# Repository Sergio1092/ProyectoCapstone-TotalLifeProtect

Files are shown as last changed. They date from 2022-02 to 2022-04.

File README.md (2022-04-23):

# **Monitoreo de la calidad del aire utilizando como indicadores la concentración de CO, CO2 y GLP**



## Proyecto Capstone del Diplomado "Internet de las Cosas" de Samsung Innovation Campus y CodigoIoT.

> Integrantes: 
> 
> Cruz Varela Karen Guerlain, UAM Azcapotzalco, Ing. en Computación.
> 
> Zárate Chávez Tania Guadalupe, UAM Azcapotzalco, Ing. en Computación.
> 
> Delgadillo Marín Sergio, UAM Azcapotzalco, Ing. en Computación.
> 
> - Asesor: Vilchis León Paloma Alejandra. 
> 
> Para **contactar** a cualquier integrante, lo puedes hacer a través de correo electrónico:
> 
> **Tania Zárate:** zarate.tania.ch@gmail.com
> 
> **Sergio Delgadillo:** al2162000251@azc.uam.mx, sergio.delgadillo@cinvestav.mx
> 
> **Karen Cruz:** karenmuse.99@gmail.com

# Introducción

Cuando se detecta cierta cantidad de humo y una cantidad de CO alto hace que esto sea nocivo para la salud, lo cual puede provocar:
- Intoxicación.
- Asfixia.
- Crisis nerviosa.
- Tos.
- Entre otros.

La **intoxicación por monóxido de carbono** sucede cuando se acumula CO en el torrente sanguíneo. Cuando hay demasiado monóxido de carbono en el aire, el cuerpo reemplaza el oxígeno en los glóbulos rojos con monóxido de carbono. Esto puede generar un **daño grave** en el tejido, o incluso desmayos y, en el peor de los casos, **muerte por asfixia**. Para evitar llegar a tal tragedia, es altamente recomendable tener el *espacio ventilado*, de esta manera, se evita la acumulación de monóxido de carbono en el lugar donde se resida o donde se labore.

Al igual que el monóxido de carbono, el **gas licuado de petróleo (GLP)**, que es una mezcla de propano y butano, al inhalarlo puede causar *euforia, somnolencia, inconsciencia, asfixia, trastornos del ritmo cardíaco, fluctuaciones en la presión sanguínea*, y puede resultar en la **muerte por _asfixia_ y fibrilación ventricular**.

Por otro lado, la pandemia mundial actualmente en curso derivada de la enfermedad ocasionada por el virus *SARS-CoV-2*, continúa afectando a la humanidad, a pesar de contar con alguna vacuna o el esquema de vacunación completo. Los contagios no sólo se han dado por la interacción entre personas, también es debido a la inhalación de partículas en el aire que contienen el virus, más en habitaciones que no cuentan con la ventilación adecuada, ya sea que no cuenten con aire acondicionado o simplemente que no tengan ventanas. Se pueden analizar los **niveles de CO2** para saber si la habitación se está llenando de *exhalaciones infecciosas*. El nivel de este componente permite estimar si entra suficiente aire fresco del exterior.

En cuanto a la relación con PNUD, el proyecto como tal se encuentra ubicado en el tercer objetivo de Desarrollo Sostenible, el cual es “Salud y Bienestar”, ya que Total Life Protect permite la **detección de humo, gas, CO y CO2** que pueden llegar a afectar al ser humano dentro del hogar debido a un mal uso de electrodomésticos o dispositivos necesarios en la vida diaria, además de evitar contagios y posibles muertes por el virus SARS-CoV-2 ya que determina la calidad del aire.

# Alcances

Se propone elaborar un **sistema de de monitoreo en casa**, la cual incluye un detector de humo, CO, CO2 y gas LP con activación de alarma; además, se le notificará a los dueños del hogar mediante un mensaje de texto a través de Telegram sobre el incidente, de tal manera que la persona tenga conocimiento de lo sucedido y así, tomar las medidas necesarias para evitar contagios y propagación del virus SARS-CoV-2 ya que, si se tiene un nivel alto de CO2, el virus podría esparcirse, así como muertes por intoxicación y asfixia debido a las altas concentraciones de los gases.

# Justificación

La manera en la que el **IoT** se relaciona con **_“Monitoreo de la calidad del aire utilizando como indicadores la concentración de CO, CO2 y GLP”_** es debido a que, por medio de Internet, se le notifica al usuario cuando ocurre algún incidente en casa o si existe alta concentración de CO, gas GLP y CO2, lo cual es una señal de que la _ventilación es deficiente_ y aumenta la probabilidad de contagio del virus SARS-CoV-2, así como muerte por asfixia o intoxicación, y de esta manera, también poder intercambiar los datos obtenidos por medio de Internet, y de esta manera, existe una comunicación entre personas y dispositivos del hogar.

# Objetivo

Diseñar un **dispositivo** que permita identificar de manera eficiente y oportuna el **alto nivel de concentración de _CO, gas GLP y CO2_** en los hogares, esto con la finalidad de garantizar la protección de la vida del ser humano.

# Material necesario

Para la elaboración del circuito, se necesita el siguiente material:

- **ESP32-CAM OV2640 Wifi Bluetooth.**                       1       $220.11
- **Convertidor USB Serial FTDI TTL FT232RL.**               1       $98.00
- **Cable USB a Mini USB Tipo B.**                           1       $64.00
- **Módulo Detector de Calidad de Aire MQ-135.**             1       $98.00 
- **Módulo Detector de Monóxido de Carbono MQ-7.**           1       $96.00 
- **Módulo Detector de Gas LP MQ-2.**                        1       $77.32
- **Módulo Ads1115.**                                        1       $161.00
- **Fuente de Alimentación 5V 2A / 9V 1A / 12V 1A.**         1       $62.00
- **Led Amarillos 5mm.**                                     5       $15.00
- **Led Rojos 5mm.**                                         5       $15.00
- **Led Verdes 5mm.**                                        5       $15.00
- **Cables Dupont Largos h-h (hembra-hembra).**              40      $93.00
- **Buzzer.**                                                1       $36.00
- **Resistencias.**          

Dentro del software necesario, se ocupará:

- **Arduino IDE.**
- **MQTT.**
- **Node-red.**
- **Telegram.**
- **MySQL.**
- **Grafana.**

# Explicación detallada del Detector de CO, CO2 GLP

El dispositivo que se propone estará en una caja estanca tipo IP67, en donde ésta contendrá los sensores necesarios para la detección de CO, gas GLP y CO2 (MQ-7, MQ-2 y MQ-135 respectivamente), la ESP32-CAM, el convertidor analógico digital, las resistencias, buzzer y sus conexiones con dichos sensores por medio de los cables dupont.
En la parte superior se encuentran los 3 LEDs (verde, amarillo y rojo), en donde su funcionamiento es el siguiente:





# Funcionamiento esperado del Sistema de monitoreo de la calidad del aire utilizando como indicadores la concentración de CO, CO2 y GLP

Existen dos formas en las que opera el dispositivo detector, las cuales son:

1. ONLINE

Dependiendo de los datos que capture el dispositivo, son los mensajes que se enviarán al usuario a través de un teléfono celular, en donde en cualquier momento será notificado de algún incidente o peligro en casa. Los mensajes que se mostrarán son los siguientes:

- Calidad del aire buena.
- Calidad del aire baja, posible contaminación por humo.
- Calidad del aire media, posible contaminación por falta de ventilación.
- Calidad del aire mala, posible contaminación por fuga de gas GLP.
- Ventilar de inmediato y verificar fugas de gas.

De igual manera, todos los datos leídos por el detector se envían por medio de MQTT a Node-red, en donde se realiza la conexión con la base de datos la cual después está ligada a Grafana que ayudará a visualizar de manera gráfica todos los valores que se han estado registrando.

2. OFFLINE

De forma independiente a si se recibieron los mensajes por la aplicación, el dispositivo cuenta con una alerta audible y visual que alertarán al usuario. Las acciones se realizan de la siguiente manera:

- Calidad del aire buena: Enciende el LED verde.
- Calidad del aire media: Enciende el LED amarillo.
- Calidad del aire mala: Enciende el LED amarillo y suenan pitidos cortos.
- Calidad del aire mala (extremadamente peligrosa): Enciende el LED rojo y suenan pitidos largos.

# Circuito a realizar

El circuito del detector se ve de la siguiente manera: 



# Conclusiones

Como resultado del desarrollo de este trabajo, se pueden mencionar las siguientes conclusiones: 

- Mediante el prototipo desarrollado fue posible obtener notificaciones oportunas sobre la calidad del aire en la habitación, esto permite realizar las acciones necesarias antes de que la mala calidad del aire se vuelva un riesgo a la salud. 
- El prototipo desarrollado es capaz de funcionar tanto con conexión a Internet como sin ella, sin embargo, no cuenta con actuadores para realizar las acciones necesarias para controlar la calidad del aire.
- El prototipo requiere de ajustar los parámetros de los sensores para funcionar correctamente en el lugar donde se instale por primera vez, las actualizaciones se realizan mediante una PC vía serial por lo que es necesario destapar el dispositivo para ponerlo en marcha.
- Mediante el software de Grafana es posible monitorear y analizar la concentración de los gases presentes en tiempo real.  

# Trabajo a futuro

En este trabajo se obtuvieron resultados satisfactorios ya que el prototipo desarrollado nos permite monitorear la calidad del aire en el entorno. No obstante, aún quedan problemas por abordar al finalizar este trabajo, de tal forma que en trabajos futuros se pretende:  

- Implementar un sistema de control retroalimentado para regular la calidad del aire.
- Implementar actuadores que permitan ventilar las habitaciones o filtrar el aire. 
- Haciendo uso de la cámara disponible en la ESP32CAM implementar un sistema de monitoreo de la afluencia de personas en la habitación y mostrar notificaciones sobre posibles aglomeraciones.  
- Implementar actualizaciones de software vía OTA.  
- Implementar redes neuronales dinámicas para realizar la identificación de la dinámica de los sensores y actualizar los parámetros del sistema en tiempo real.  
- Evaluar la implementación de sensores que permitan obtener una lectura cuantitativa de la concentración de los gases. 

# Referencias

- ¿Por qué la concentración de CO2 en un lugar puede ser indicador de riesgo de contagio de COVID-19? (s. f.). Recuperado 17 de octubre de 2021, de https://www.aa.com.tr/es/mundo/-por-qu%C3%A9-la-concentraci%C3%B3n-de- co2-en-un-lugar-puede-ser-indicador-de-riesgo-de-contagio-de-covid-19/2158723
- Cómo puede afectar la salud el humo de los incendios. (2020, 14 octubre). US EPA. Recuperado 17 de octubre de 2021, de https://espanol.epa.gov/espanol/como- puede-afectar-la-salud-el-humo-de-los-incendios
- 40 Cables Dupont Pin Para Protoboard Hembra - Hembra 25cm. (s. f.). Mercado Libre. Recuperado 19 de octubre de 2021, de https://articulo.mercadolibre.com.mx/MLM-1303560141-40-cables-dupont-pin-para-protoboard-hembra-hembra-25cm-_JM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
- Incendios urbanos en México. – CONAPCI. (s. f.). CONAPCI. Recuperado 17 de octubre de 2021, de https://conapci.org/incendios-urbanos-en-mexico/
- Intoxicación con monóxido de carbono - Síntomas y causas - Mayo Clinic. (2019, 16 octubre). Recuperado 17 de octubre de 2021, de https://www.mayoclinic.org/es-es/diseases-conditions/carbon-monoxide/symptoms-causes/syc-20370642
- Miller, S. (2020, 28 agosto). ¿Cómo puedes utilizar la ventilación para prevenir la propagación de COVID-19 dentro de tu casa? The Conversation. Recuperado 17 de octubre de 2021, de https://theconversation.com/como-puedes-utilizar-la-ventilacion-para-prevenir-la-propagacion-de-covid-19-dentro-de-tu-casa-1444564
- Esp32 Cam Ov2640 Wifi Bluetooth Cdmx Electrónica. (s. f.). Mercado Libre. Recuperado 19 de octubre de 2021, de https://articulo.mercadolibre.com.mx/MLM-694802972-esp32-cam-ov2640-wifi-bluetooth-cdmx-electronica-_JM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
- Módulo Mq135 Sensor De Calidad Del Aire Nh3 Nox Benceno Co2. (s. f.). Mercado Libre.           Recuperado    19        de        octubre           de                     2021, de https://articulo.mercadolibre.com.mx/MLM-588244581-modulo-mq135-sensor-de-calidad-del-aire-nh3-nox-benceno-co2-_JMmatt_tool=40183013&matt_word&matt_source=google&mat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
- Modulo Tipo Mq-7 Sensor Detector De Monóxido De Carbono. (s. f.). Mercado Libre. Recuperado 19 de octubre de 2021, de https://articulo.mercadolibre.com.mx/MLM-1316472692-modulo-tipo-mq-7-sensor-detector-de-monoxido-de-carbono-_JM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
- ESP32-CAM: lo que debes saber sobre éste modulo. (s. f.). Hardwarelibre. Recuperado 01 de marzo de 2022, de https://www.hwlibre.com/esp32-cam/
- El sensor de CO2 MQ-135 analizado al detalle. (s. f.). Iberotecno. Recuperado 01 de marzo de 2022, de https://iberotecno.com/tienda/blog/electronica/el-sensor-de-co2-mq-135-analizado-al-detalle
- MQ2 Sensor de Gas Humo Propano. (s. f.). MarkerElectronico. Recuperado 01 de marzo de 2022, de https://www.makerelectronico.com/producto/mq2-sensor-de-gas-humo-arduino-propano/
- ADS1115 convertidor analógico digital ADC para Arduino y ESP8266. (s. f.).  Programarfácil. Recuperado 01 de marzo de 2022, de https://programarfacil.com/blog/arduino-blog/ads1115-convertidor-analogico-digital-adc-arduino-esp8266/
- Zumbador o buzzer con Arduino y librería EasyBuzzer. (s. f.).  Programarfácil. Recuperado 01 de marzo de 2022, de https://programarfacil.com/blog/arduino-blog/buzzer-con-arduino-zumbador/

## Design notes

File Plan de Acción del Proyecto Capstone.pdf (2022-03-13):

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

HOJA 1 / 4 | | 55 8590 8505
www.CodigoIoT.com | | | Morelos 53, Del Carmen, Coyoacán, CDMX. Factor Evolución SA de CV

Elaborado para: Código IoT

Fecha de elaboración: 12 de marzo de 2022

Vigencia: 30 días naturales

Elaborado por:

Revisado por:

Hugo Vargas

Paloma Vilchis y Hugo Vargas

Documento: Plan de Acción del Proyecto Capstone

HOJA 2 / 4 | 55 8590 8505

## Formato Kardex

### Alumnos

Nombre del proyecto: | Monitoreo de la calidad del aire utilizando como indicadores la con-
centración de CO, CO2 y GLP.

Fecha de inicio del proyecto:

20 de septiembre de 2021

Fecha de conclusión del
proyecto:

10 de marzo de 2022

Descripción: | Se propone elaborar un sistema de monitoreo en casa-habitación,
el cual incluye un detector de humo, CO, CO2 y gas LP con activación de alarma y envío de mensajes mediante la aplicación Telegram.
Aplicaciones: | • | Verificación constante de la calidad de aire.
- Detección oportuna de incidentes ocurridos en el espacio
| | donde se encuentre instalado.
- Envío de mensajes.
- Prevención de riesgos.
Objetivo general: | Diseñar un dispositivo que permita identificar de manera eficiente
y oportuna el alto nivel de CO, gas GLP y CO2 en los hogares, esto con la finalidad de garantizar la protección de la vida del ser hu-
| mano.
Objetivos específicos: | • | Mostrar los valores de concentración de CO, CO2 y gas GLP.
- Indicar el estado del aire.
- Alertar por medio de un zumbador/buzzer cuando se en-
| | cuentre un nivel alto de concentración de gases.
- Notificar por medio de Telegram cualquier anomalía que se
| | presente.
- Concientizar al ser humano sobre los efectos que genera la
| | gran concentración de CO, gas GLP y CO2.
Justificación: | La manera en la que el IoT se relaciona con el proyecto es debido a
que, por medio de Internet, se le notifica al usuario cuando ocurre algún incidente en casa o si existe alta concentración de CO, gas GLP y CO2, lo cual es una señal de que la ventilación es deficiente y aumenta la probabilidad de contagio del virus SARS-CoV-2, así como muerte por asfixia o intoxicación, y de esta manera, también poder

HOJA 3 / 4 | 55 8590 8505

intercambiar los datos obtenidos por medio de Internet, de esta manera, existe una comunicación entre personas y dispositivos del hogar.

En cuanto a la relación con PNUD, el proyecto como tal se encuentra ubicado en el tercer objetivo de Desarrollo Sostenible, el cual es “Salud y Bienestar”, ya que el proyecto permite la detección de humo, gas, CO y CO2 que pueden llegar a afectar al ser humano dentro del hogar debido a un mal uso de electrodomésticos o dispositivos necesarios en la vida diaria, además de evitar contagios y posibles muertes por el virus SARS-CoV-2 ya que determina la calidad del aire.

Integrantes del equipo: | Cruz Varela Karen Guerlain. Delgadillo Marín Sergio. Zárate Chávez Tania Guadalupe.
Validado por: | Vilchis León Paloma Alejandra.
Contenido Temático: | Temario
1. Introducción
2. Justificación
3. Objetivos
4. Lista de material
5. Detalles de los componentes
6. Circuito a realizar
7. Funcionamiento esperado
8. Programa
9. Instrucciones de operación de proyecto
10. Fotografías del proyecto funcional
11. Conclusiones
12. Trabajos a futuro
Productos: | Prototipo de detector de altas concentraciones de humo, CO, CO2 y GLP.
Alcances: | Construir un sistema de monitoreo de la calidad del aire para pre- venir accidentes/aglomeraciones en una casa-habitación en un plazo no mayor a 9 meses y de acuerdo a las especificaciones técni- cas del documento adjunto.

HOJA 4 / 4 | 55 8590 8505
Requisitos: | Se recomienda tener conocimientos básicos de programación en
C/C++, protocolo MQTT y bases de datos.
Software: | • | Arduino IDE.
- Grafana.
- MySQL.
- Node-Red.
- Telegram.
Hardware: | • | ESP32-CAM OV2640 Wifi Bluetooth
- Convertidor USB Serial FTDI TTL FT232RL
- Cable USB a Mini USB Tipo B
- Módulo Detector de Calidad de Aire MQ-135
- Módulo Detector de Monóxido de Carbono MQ-7
- Módulo Detector de Gas MQ-2
- Módulo ADS1115
- Fuente de Alimentación 5V 2A / 9V 1A / 12V 1A
- Led (https://edu.codigoiot.com/mod/glossary/showentry.php?eid=25&displayformat=dictionary) Amarillos, Rojos y Verdes 5mm
- Cables Dupont Largos h-h (hembra-hembra)
- Buzzer
- Resistencias

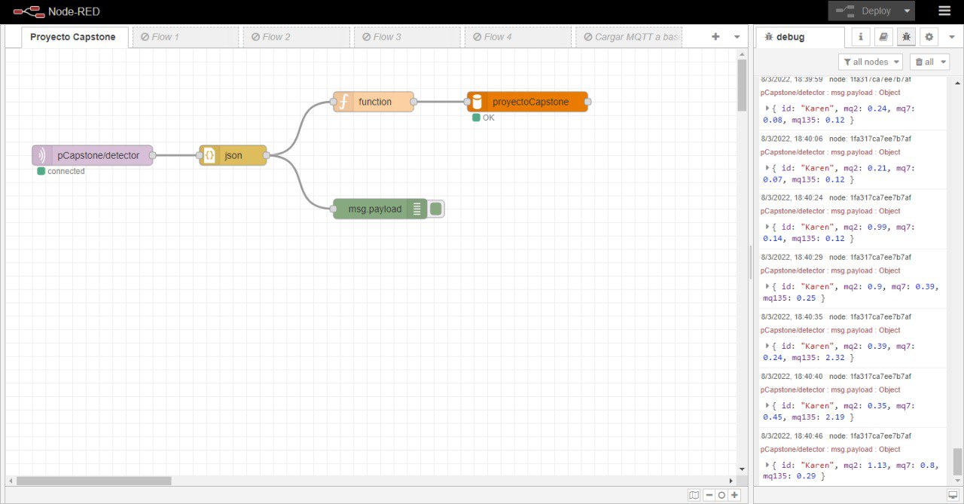
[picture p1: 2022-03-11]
Fotografías del Proyecto/Node-Red.jpeg

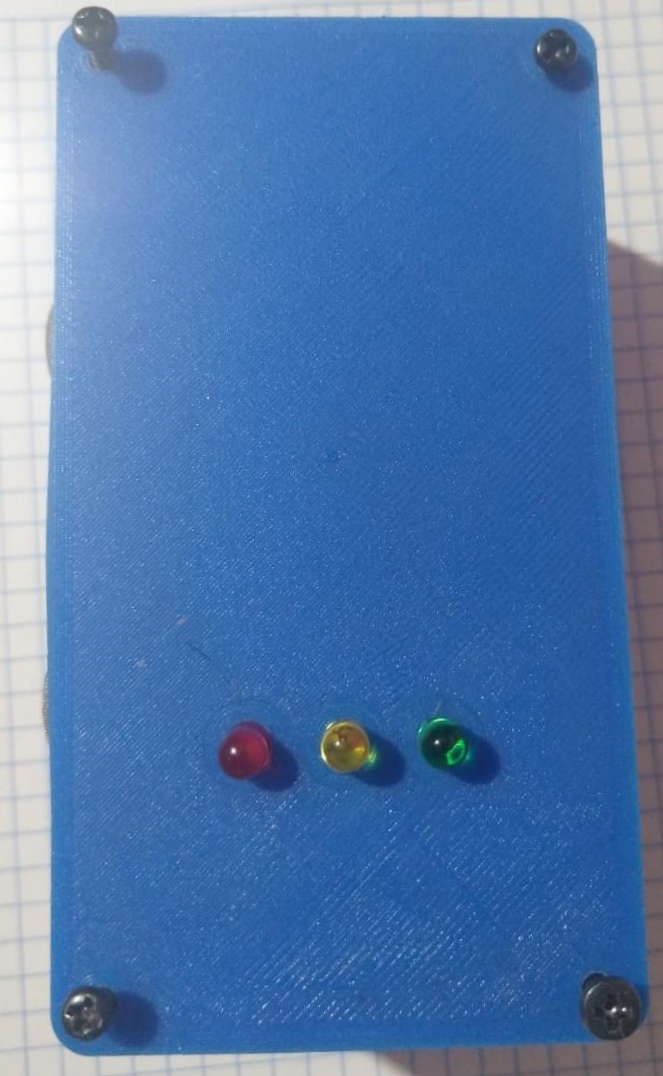
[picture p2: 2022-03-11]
Fotografías del Proyecto/Detector CO-CO2-GLP (3).jpeg

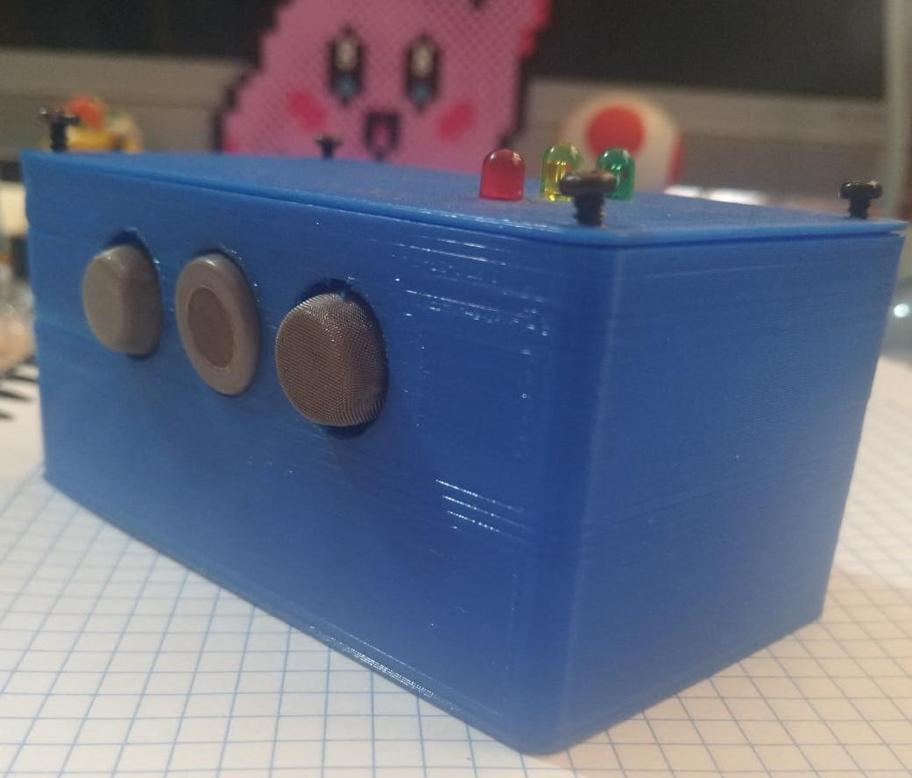
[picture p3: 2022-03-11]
Fotografías del Proyecto/Detector CO-CO2-GLP (2).jpeg

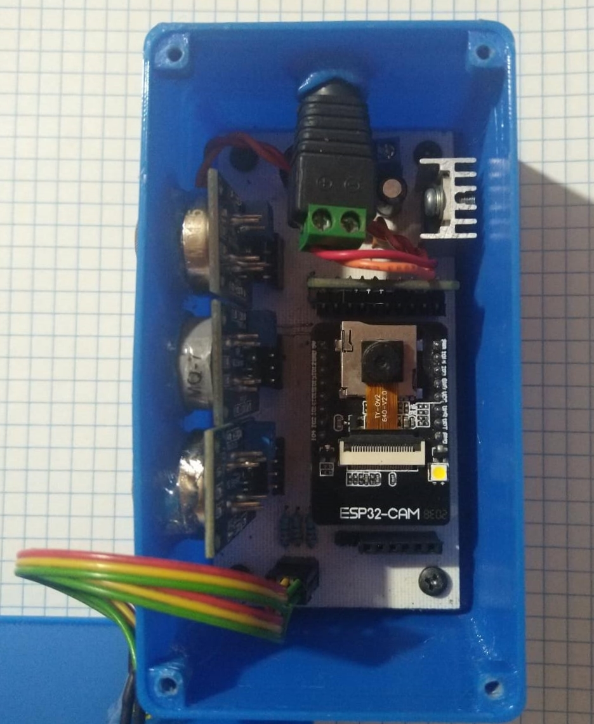
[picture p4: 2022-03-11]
Fotografías del Proyecto/Detector CO-CO2-GLP (4).jpeg

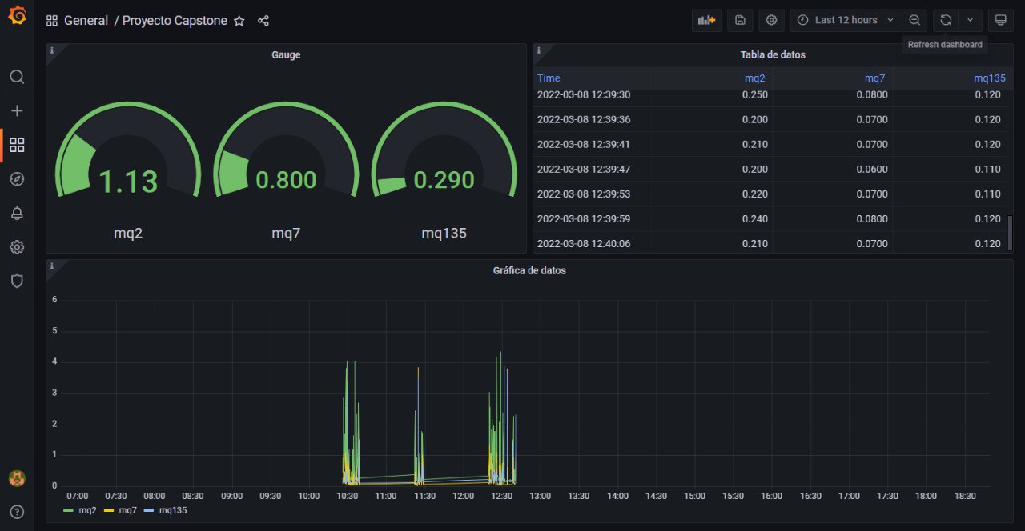
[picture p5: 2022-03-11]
Fotografías del Proyecto/Grafana.jpeg

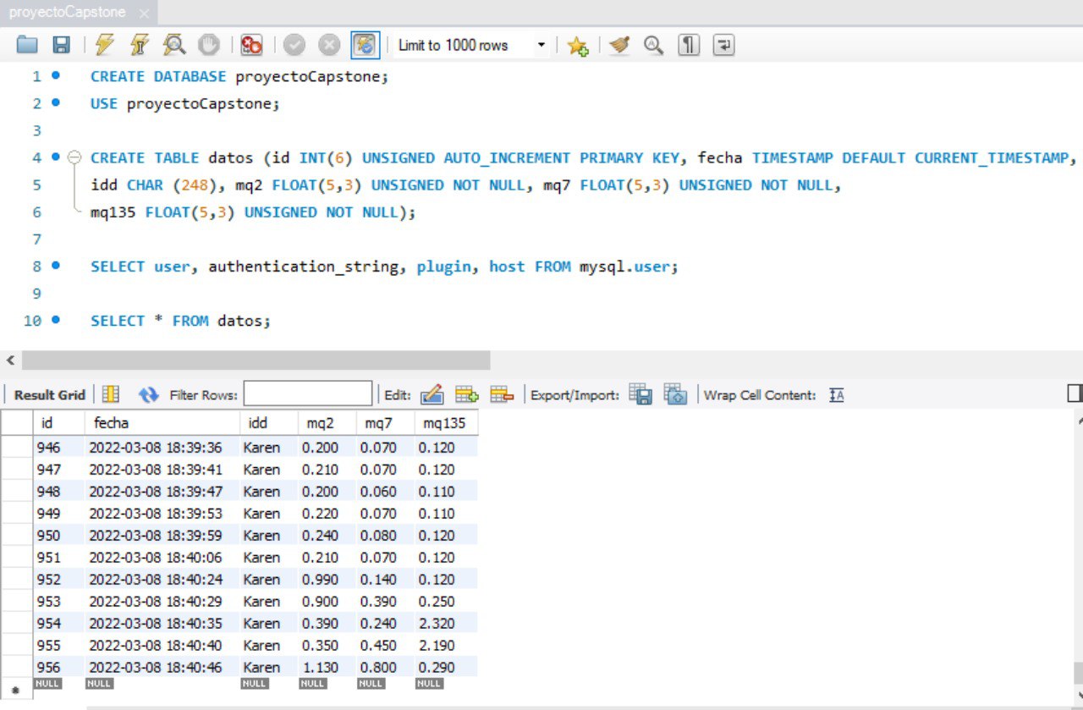
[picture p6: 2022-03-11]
Fotografías del Proyecto/MySQL.jpeg

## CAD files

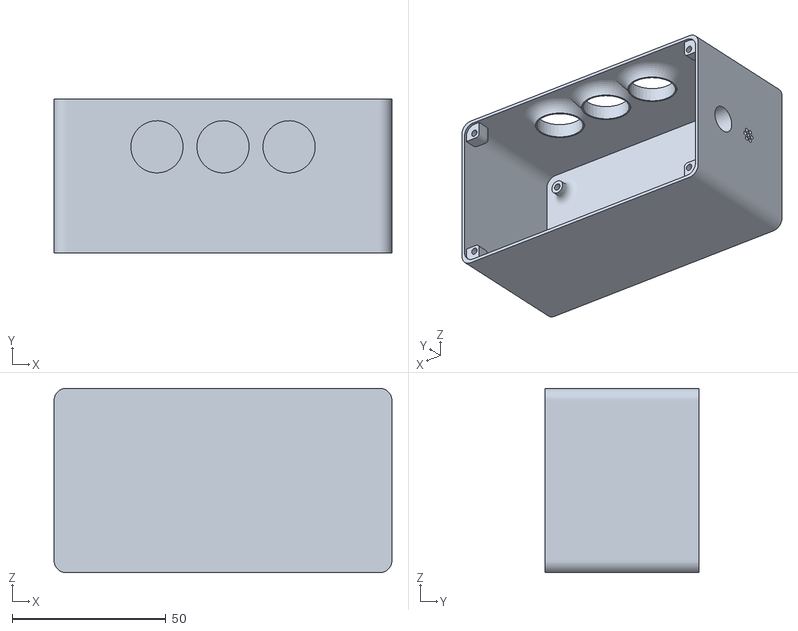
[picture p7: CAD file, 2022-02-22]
Gabinete3D_Detector/gabinete.STL
110.0 x 50.0 x 60.0

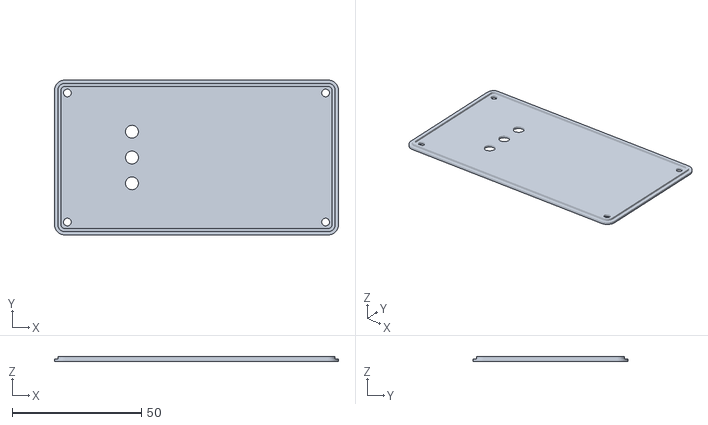
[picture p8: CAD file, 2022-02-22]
Gabinete3D_Detector/tapa_gabinete.STL
110.0 x 60.0 x 2.00

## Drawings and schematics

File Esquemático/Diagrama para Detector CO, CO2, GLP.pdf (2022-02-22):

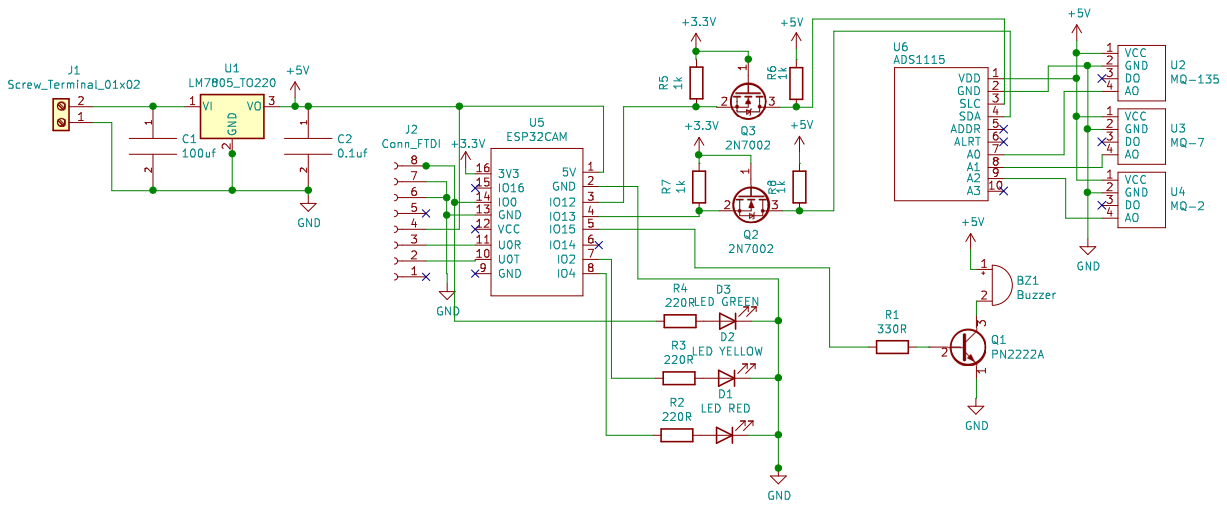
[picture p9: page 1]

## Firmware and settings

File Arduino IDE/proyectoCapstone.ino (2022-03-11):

/*
   Envio de JSON por MQTT.
   por: Hugo Escalpelo
   Fecha: 15 de noviembre de 2021

   Editado por: Karen Cruz, Sergio Delgadillo, Tania Zárate
   Fecha: 25 de febrero de 2022

   Proyecto Capstone:
   Monitoreo de la calidad del aire utilizando como indicadores la concentración de 
   CO, CO2 y GLP

   Este programa envía datos por Internet a través del protocolo MQTT. Para poder
   comprobar el funcionamiento de este programa, es necesario conectarse a un broker
   y usar Node-Red para visualzar que la información se está recibiendo correctamente.
   Este programa no requiere componentes adicionales.

   Este programa está basado en "Conexión básica por MQTT del NodeMCU" y explica como
   enviar strings que contengan JSON para enviar mas de una variable a la vez.

   Por otra parte, los datos obtenidos de los sensores MQ-2, MQ-7 y MQ-135 son
   analizados de tal manera que, dependiendo del nivel en el que se encuenten,
   son los mensajes que se enviarán a través de un bot de Telegram.
*/

// Bibliotecas
#include <WiFi.h>  // Biblioteca para el control de Wi-Fi
#include <PubSubClient.h> // Biblioteca para conexion MQTT
#include <Wire.h> // Biblioteca para la comunicación con dispositivos I2C/TWI
#include <WiFiClientSecure.h>
#include <Adafruit_ADS1X15.h> // Biblioteca para ADC ADS1115
#include <UniversalTelegramBot.h> // Biblioteca para la conexión con Telegram
#include <ArduinoJson.h> // Biblioteca para generar datos JSON

// Set pin numbers
#define POWER_PIN  12
#define SIGNAL_PIN 13
#define LED_Y 2
#define LED_G 0
#define LED_R 14
#define BUZZER 15

// I2C
#define I2C_SDA 13 // Conectar SDA a GPIO 13
#define I2C_SCL 12 // Conectar SCL a GPIO 12
TwoWire I2CSensor = TwoWire(0); // Definición de puerto Wire

//Datos de WiFi
#define WIFI_SSID "Nombre" // Nombre de la red
#define WIFI_PASSWORD "Contraseña" // Contraseña de la red

// BOT de Telegram (IDBot y BotFather)
String chatId = "1111111111"; // ID de Telegram
#define BOT_TOKEN "1111111111:11111111111111111111111111111111111" // Token del BOT
WiFiClientSecure secured_client;
UniversalTelegramBot bot(BOT_TOKEN, secured_client);

// Variables globales
float volts0, volts1, volts2;
float MQ2, MQ7, MQ135;
unsigned long t = 0;
unsigned long t2 = 10000; // Retardo de tiempo para el envio de mensajes ok
int n = 10;
int dt = 100;
String msg;
// Rango de voltajes para los sensores MQ2, MQ7 y MQ135
float u[3][3] =
{ {0.9, 0.31, 0.36},
  {1.96, 0.43, 0.57},
  {3.0, 3.0, 3.0}
}; 

//Datos del broker MQTT
const char* mqtt_server = "52.28.133.146"; // Colocar la dirección IP de la red local o pública
IPAddress server(52,28,133,146);

// Objetos
WiFiClient espClient; // Este objeto maneja los datos de conexion Wi-Fi
PubSubClient client(espClient); // Este objeto maneja los datos de conexion al broker
Adafruit_ADS1115 ads;  // ADS1115 16-bit version

// Variables
long timeNow, timeLast; // Variables de control de tiempo no bloqueante
int wait = 5000;  // Indica la espera cada 5 segundos para envío de mensajes MQTT

// Inicialización del programa
void setup() {
  // Iniciar comunicación serial
  Serial.begin (115200);
  pinMode (POWER_PIN, OUTPUT);
  digitalWrite (POWER_PIN, HIGH);

  // Configuración de LED's y Buzzer como salida
  pinMode(LED_G, OUTPUT);
  pinMode(LED_Y, OUTPUT);
  pinMode(LED_R, OUTPUT);
  pinMode(BUZZER, OUTPUT);

  // Configuración de LED's y Buzzer como apagado
  digitalWrite(BUZZER, LOW);
  digitalWrite(LED_G, LOW);
  digitalWrite(LED_R, LOW);
  digitalWrite(LED_Y, LOW);

  Serial.println();
  Serial.println();
  Serial.print("Conectar a ");
  Serial.println(WIFI_SSID); // Se indica la red a la cual se va a conectar

  WiFi.begin(WIFI_SSID, WIFI_PASSWORD); // Esta es la función que realiza la conexión a WiFi
  secured_client.setCACert(TELEGRAM_CERTIFICATE_ROOT); // Agregar certificado raíz para api.telegram.org
  while (WiFi.status() != WL_CONNECTED) { // Este bucle espera a que se realice la conexión
    digitalWrite (POWER_PIN, HIGH);
    delay(500); // Dado que es de suma importancia esperar a la conexión, debe usarse espera bloqueante
    digitalWrite (POWER_PIN, LOW);
    Serial.print(".");  // Indicador de progreso
    delay(5);
  }

  // Cuando se haya logrado la conexión, el programa avanzará, por lo tanto, puede informarse lo siguiente
  Serial.println();
  Serial.println("WiFi conectado");
  Serial.println("Direccion IP: ");
  Serial.println(WiFi.localIP()); // Muestra la dirección IP

  Serial.print("Retrieving time: ");
  configTime(0, 0, "pool.ntp.org"); // Obtener la hora UTC a través de NTP
  time_t now = time(nullptr);
  while (now < 24 * 3600) {
    Serial.print(".");
    delay(100);
    now = time(nullptr);
  }
  Serial.println(now);

  I2CSensor.begin(I2C_SDA, I2C_SCL, 100000);
  if (!ads.begin(0x48, &I2CSensor)) { // Inicialice ADS1115 en la dirección 0x48
    Serial.println("Couldn't Find sensor ADS1115."); // El sensor ADS1115 no fue encontrado
    bot.sendMessage(chatId, "Couldn't Find sensor ADS1115.\n");
    while(1);
  }
  else {
    bot.sendMessage(chatId, "Modulo TLP 1 listo.");
    Serial.println("Sensor ADS1115 Found");
  }

  //Se enciende tanto el buzzer como el led verde para indicar que el módulo se encuentra listo para usarse
  digitalWrite(BUZZER, HIGH);
  delay(1000);
  digitalWrite(BUZZER, LOW);
  digitalWrite(LED_G, HIGH);
  t = millis();

  delay (1000); // Esta espera es solo una formalidad antes de iniciar la comunicación con el broker

  // Conexión con el broker MQTT
  client.setServer(server, 1883); // Conectarse a la IP del broker en el puerto indicado
  delay(1500);  // Esta espera es preventiva, espera a la conexión para no perder información

  timeLast = millis (); // Inicia el control de tiempo
}// fin del void setup ()

// Cuerpo del programa, bucle principal
void loop(void) {
  MQ2 = 0;
  MQ7 = 0;
  MQ135 = 0;
  // Lectura de sensores
  for (int i = 0; i < n; i++) {
    // Los valores obtenidos por los sensores son convertidos en volts 
    MQ2 += ads.computeVolts(ads.readADC_SingleEnded(0)) / n;
    MQ7 += ads.computeVolts(ads.readADC_SingleEnded(1)) / n;
    MQ135 += ads.computeVolts(ads.readADC_SingleEnded(2)) / n;
    delay(dt);
  }
  Serial.print("MQ2: "); Serial.print(MQ2);
  Serial.print(", MQ7: "); Serial.print(MQ7);
  Serial.print(", MQ135: "); Serial.println(MQ135);

  // Si los sensores sobrepasan el último rango, significa que la calidad del aire es mala
  // Si MQ2, MQ7 o MQ135 es mayor a 3.0 
  if (MQ2 > u[2][0] || MQ7 > u[2][1] || MQ135 > u[2][2]) {
    Serial.println("Calidad del aire MALA, posible contaminación por fuga de gas LP.");
    Serial.println("Ventilar de inmediato y verificar fugas de gas.");
    bot.sendMessage(chatId, "Calidad del aire MALA, posible contaminación por fuga de gas LP.");
    bot.sendMessage(chatId, "Ventilar de inmediato y verificar fugas de gas.");
    // Se enciende el led rojo
    digitalWrite(LED_R, HIGH);
    digitalWrite(LED_G, LOW);
    digitalWrite(LED_Y, LOW);
    // Se enciende el buzzer, el sonido es largo
    digitalWrite(BUZZER, HIGH);
    delay(2000);
    digitalWrite(BUZZER, LOW);
    delay(1000);
    digitalWrite(BUZZER, HIGH);
    delay(2000);
    digitalWrite(BUZZER, LOW);

  } 
  // Si los sensores sobrepasan el rango medio, significa que la calidad del aire es baja
  // Si MQ2 > 1.96, o MQ7 > 0.43, o MQ135 > 0.57
  else if (MQ2 > u[1][0] || MQ7 > u[1][1] || MQ135 > u[1][2]) {
    Serial.println("Calidad del aire baja, posible contaminación por falta de ventilación.");
    bot.sendMessage(chatId, "Calidad del aire baja, posible contaminación por falta de ventilación.");
    // Se enciende el led amarillo
    digitalWrite(LED_Y, HIGH);
    digitalWrite(LED_G, LOW);
    digitalWrite(LED_R, LOW);
    // Se enciende el buzzer, el sonido es corto
    digitalWrite(BUZZER, HIGH);
    delay(1000);
    digitalWrite(BUZZER, LOW);
    delay(100);
    digitalWrite(BUZZER, HIGH);
    delay(1000);
    digitalWrite(BUZZER, LOW);
  } 
  // Si los sensores sobrepasan el primer rango, significa que la calidad del aire es media
  // Si MQ2 > 0.9, o MQ7 > 0.31, o MQ135 > 0.36
  else if (MQ2 > u[0][0] || MQ7 > u[0][1] || MQ135 > u[0][2]) {
    Serial.println("Calidad del aire media, posible contaminación por humo.");
    bot.sendMessage(chatId, "Calidad del aire media, posible contaminación por humo.");
    // Se enciende el led amarillo
    digitalWrite(LED_Y, HIGH);
    digitalWrite(LED_G, LOW);
    digitalWrite(LED_R, LOW);
    delay(10000);
  } else {
    // Ciclo para que el mensaje de "Calidad del aire buena" no sea muy repetitivo
    if (millis() > t + t2) {
      t = millis();
      bot.sendMessage(chatId, "Calidad del aire buena.");
      Serial.println("Calidad del aire buena.");
    }
    // Se enciende el led verde
    digitalWrite(LED_G, HIGH);
    digitalWrite(LED_R, LOW);
    digitalWrite(LED_Y, LOW);
  }
  //Verificar siempre que haya conexión al broker
  if (!client.connected()) {
    reconnect();  // En caso de que no haya conexión, ejecutar la función de reconexión, definida despues del void setup ()
  }
  else{
  client.loop(); // Esta función es muy importante, ejecuta de manera no bloqueante las funciones necesarias para la comunicación con el broker

  timeNow = millis(); // Control de tiempo para esperas no bloqueantes
  if (timeNow - timeLast > wait) { // Manda un mensaje por MQTT cada cinco segundos
    timeLast = timeNow; // Actualización de seguimiento de tiempo

    //Se construye el string correspondiente al JSON que contiene 4 variables
    String json = "{\"id\":\"Karen\",\"mq2\":" + String(MQ2) + ",\"mq7\":" + String(MQ7) + ",\"mq135\":" + String(MQ135) + "}";
    Serial.println(json); // Se imprime en monitor solo para poder visualizar que el string esta correctamente creado
    int str_len = json.length() + 1; // Se calcula la longitud del string
    char char_array[str_len]; // Se crea un arreglo de caracteres de dicha longitud
    json.toCharArray(char_array, str_len); // Se convierte el string a char array
    client.publish("pCapstone/detector", char_array); // Esta es la función que envía los datos por MQTT, especifica el tema y el valor
  }// fin del if (timeNow - timeLast > wait)
  }
}// fin del void loop ()

// Función para reconectarse
void reconnect() {
    Serial.print("Tratando de contectarse...");
    // Intentar reconexión
    if (client.connect("pCapstoneClient")) { //Pregunta por el resultado del intento de conexión
      Serial.println("Conectado");
      client.subscribe("pCapstone/output"); // Esta función realiza la suscripción al tema
    }// fin del  if (client.connect("pCapstoneClient"))
    else {  //en caso de que la conexión no se logre
      Serial.print("Conexion fallida, Error rc=");
      Serial.print(client.state()); // Muestra el codigo de error
      Serial.println (client.connected ()); // Muestra estatus de conexión
    }// fin del else
}// fin de void reconnect()

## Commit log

2022-02-08 Add firmware
    Se añadió la librería para el ADS1115 y un código de prueba para comprobar el funcionamiento del circuito
2022-02-08 3D print files
    Se añaden los archivos para imprimir el gabinete del prototipo
    [gabinete.STL, tapa_gabinete.STL]
2022-03-10 Create Tapa_Gabinete
    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
2022-03-10 Se añaden los archivos para imprimir el gabinete del detector de CO, CO2 y GLP
    [gabinete.STL, tapa_gabinete.STL]
2022-03-10 Add files via upload
    Se añade el archivo del esquemático para el detector
2022-03-10 Se añade el archivo del esquemático para el detector
2022-03-11 Add files via upload
    Se añade el programa realizado en el IDE de Arduino
2022-03-11 Se añade el programa realizado en el IDE de Arduino
2022-03-11 Se añade el archivo para la creación de la base de datos en MySQL
2022-03-11 Se añade el archivo JSON para la importación del flow en Node-red
2022-03-13 Se añade el archivo kardex del plan de acción de nuestro proyecto
